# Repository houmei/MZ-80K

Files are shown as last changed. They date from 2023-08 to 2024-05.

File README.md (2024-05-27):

# MZ-80K

## 更新履歴
2024.5.27 U4 74LS14 RESETと*RESETの入れ替わり修正  
2024.5.27 U47 74154 pin18とpin19の入れ替わり修正  
2023.9.14 訂正 CPUにINT入力追加、RAMの100pFディレイ * RAS1 → *CAS  
2023.8.20 公開  

## 機種別情報
MZ-80K2は2色LEDから赤/緑の個別LEDに変更。  
MZ-80K2/MZ-80K2EはCPUが直付け、リセット周辺回路(U31 74121)とリセットスイッチが省略。  

## 新旧基板
ロジック基板はMZ-80Kでの初期版とそれ以降の後期版が存在する。初期版と後期版の違いはROMと電源コネクタ。  
+ 初期基板 M-ROM 2708 x4、CGROM 2708 x2、電源コネクタ molex 5198/5283 (5.08mmピッチ)  
+ 後期基板 M-ROM 2532 x1、CGROM 2716 x1、電源コネクタ JST 4P-LV/B4P-LV-TA (8.0mmピッチ)

電源コネクタ情報：[@mono_Pさんより](https://twitter.com/momo_P/status/1702351033270481181)

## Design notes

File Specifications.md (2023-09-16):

#

+ CPU: Z80 2MHz
+ Memory: Monitor-ROM 4KB , RAM 48KB(Max)
+ Display: 10"CRT 40 x 25 Characters VRAM 1KB 60Hz(V),15.75kHz(H)
+ Cassete: 1200 baud
+ Weight: Approx. 13kg
+ Dimensions: 410 x 270 x 470 mm
+ PSU: DC5V 1.6Amax DC12V 1.6Amax DC-5V 0.2Amax Approx. 45W

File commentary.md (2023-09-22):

# MZ-80K 回路図解説

## CPU
+ CPU(U46 Z80)のバスバッファはU36,U37 LS241 x2、アドレスバッファはU44,U45 LS244 x2。  
+ 制御信号もU35 LS244でバッファ。  
+ CLK入力はレベルを合わせるため330Ωでプルアップ。  
+ メモリWAITは未使用。  
+ *NMI は未使用。  
+ *INT はTIMER(U18 8253)のOUT2(を反転したもの)に接続。  
+ マニュアルリセットはU31 74121によるワンショット。0.7CR = 0.7x0.01ux15k = 0.1ms。一部機種(K2Eなど)では省略。  

※CPUに直接接続されている信号は * INT 程度でかなりガードされている印象。  

## メモリ
### RAM
+ DRAM 8個 x3ブロックで最大48KB、基本は16KB。  
+ RAMブロックのうち最初のRAM1ブロックは16KB(4116 x8)、RAM2,RAM3ブロックは4KB(4027 x8)または16KB(4116 x8)の選択式。  
+ *CASはU54E,U54DのLS04 2段に加えて100pFを使用し信号を少し遅らせている。  
### RAMSEL
+ U50 LS244はM-ROMの出力とDRAMのDoutを受けてデータバスに接続。DRAMのDinはデータバスに直結。
+ U50 LS244はM-ROM/DRAMセレクトのリード時のみ開く。
+ U55B LS74出力のS1はDRAMの上位/下位アドレス切り替え。  
+ RSEL1,2,3および*RAS1,2,3はCS1ジャンパでRAMブロックの範囲を16KBまたは4KBで選択する。  
### DECODE
+ U47 74154で64KBのメモリ空間を4Kバイト単位に分割。
+ IO領域は$ExxxをU30 LS42でデコードし8255,8253をセレクト。
+ U57 74150、U58 LS00は4K DRAMに必要な論理。
+ U56 S157、U53 S157でRAS/CASアドレスを生成。

※ *CASをドライブするU54D LS04の負荷は重いのではないか？  
※U54E LS04とU54D LS04の間に100pFを入れてもよかったのでは  

## ビデオ

## I/O

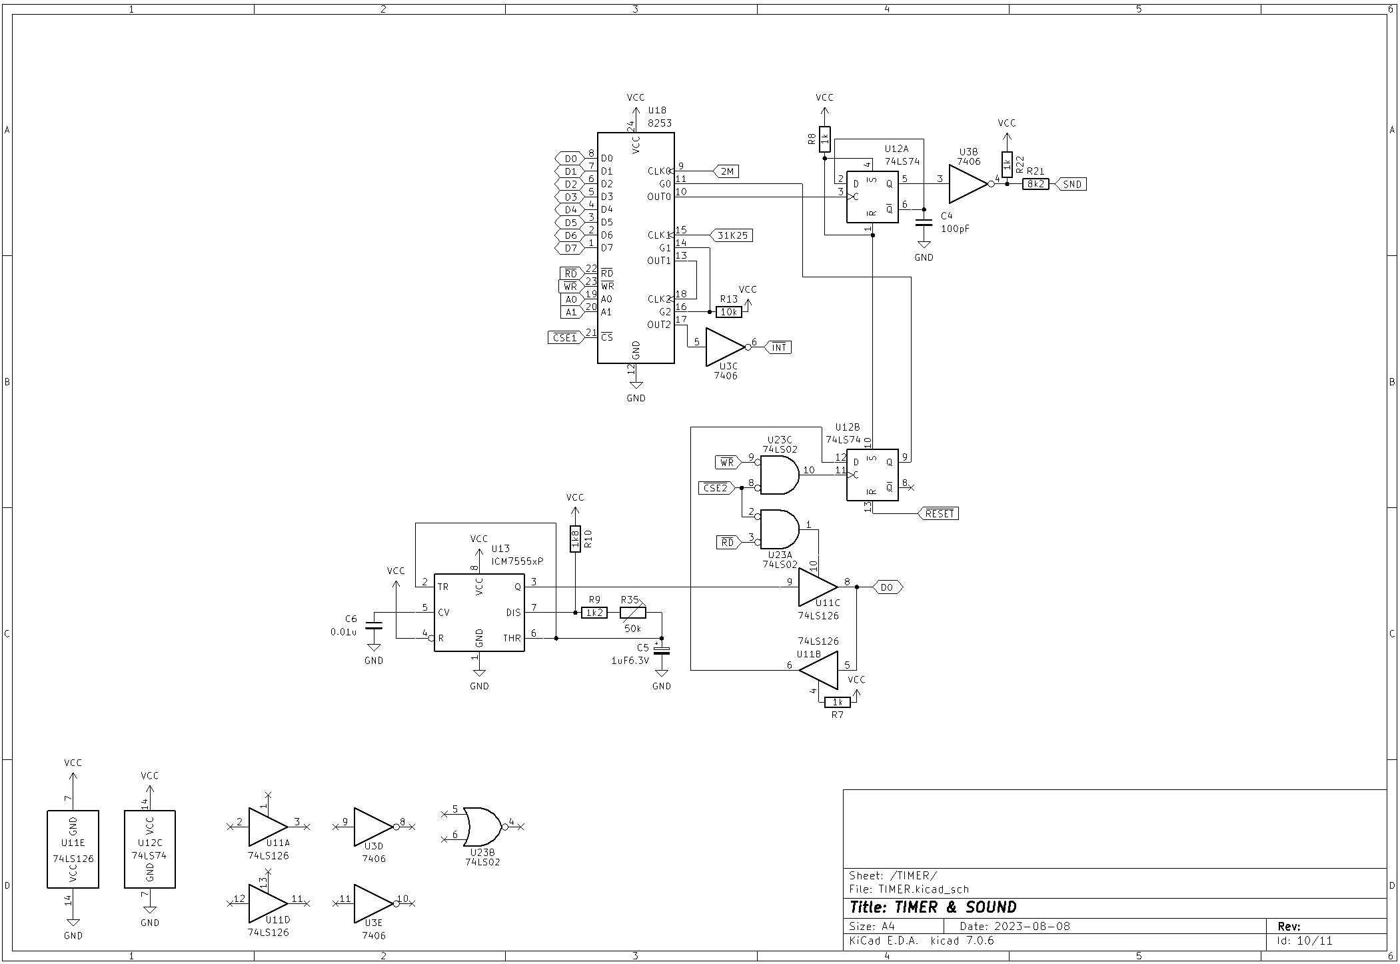
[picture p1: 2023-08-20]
img/10TIMER.png

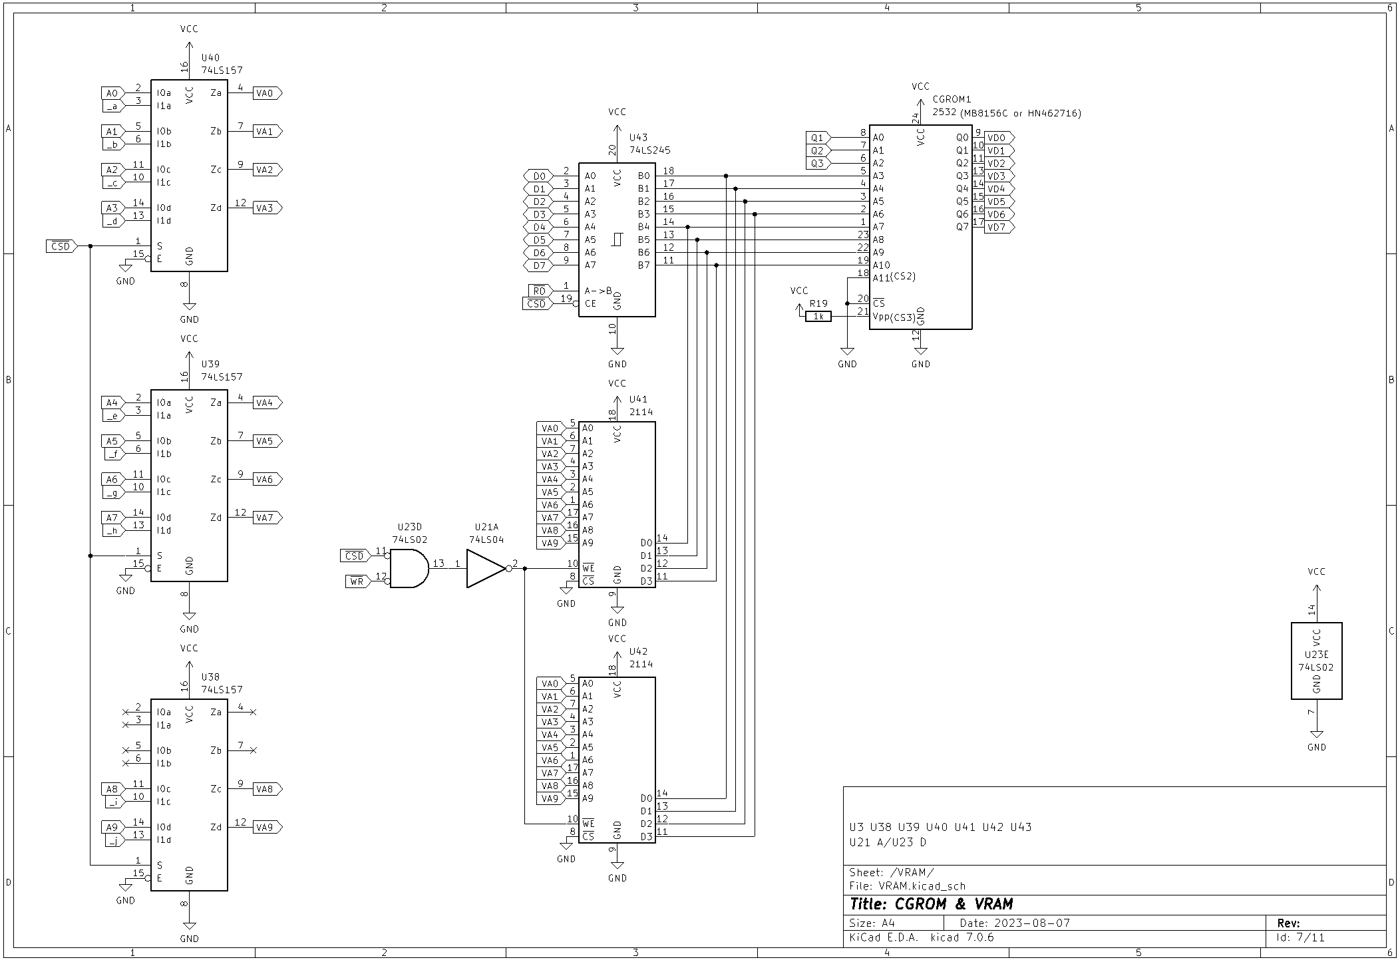
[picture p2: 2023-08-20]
img/07VRAM.png

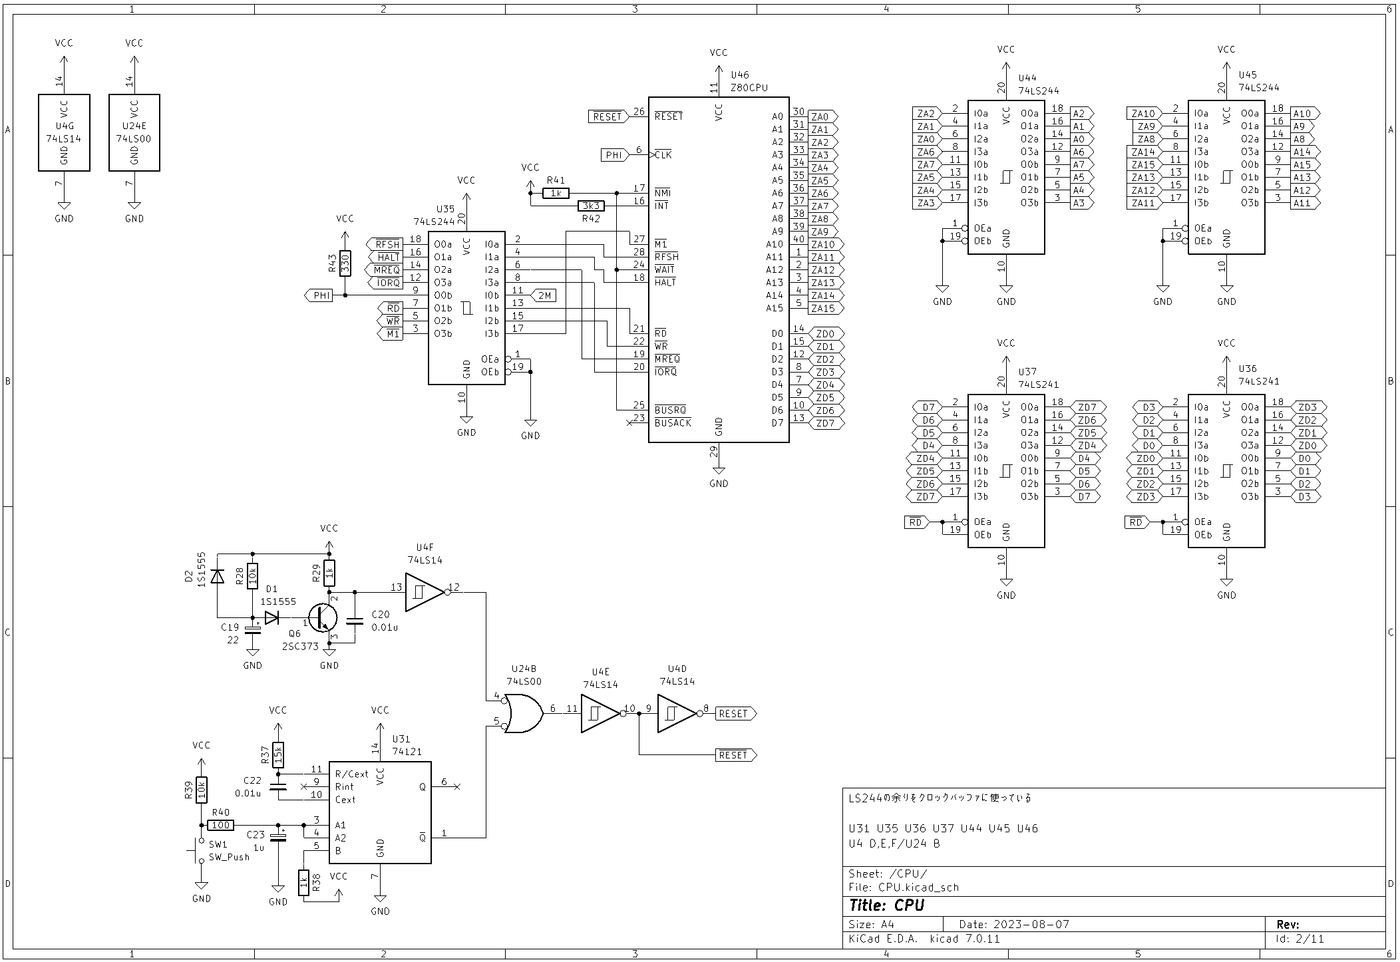
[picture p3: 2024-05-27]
img/02CPU.png

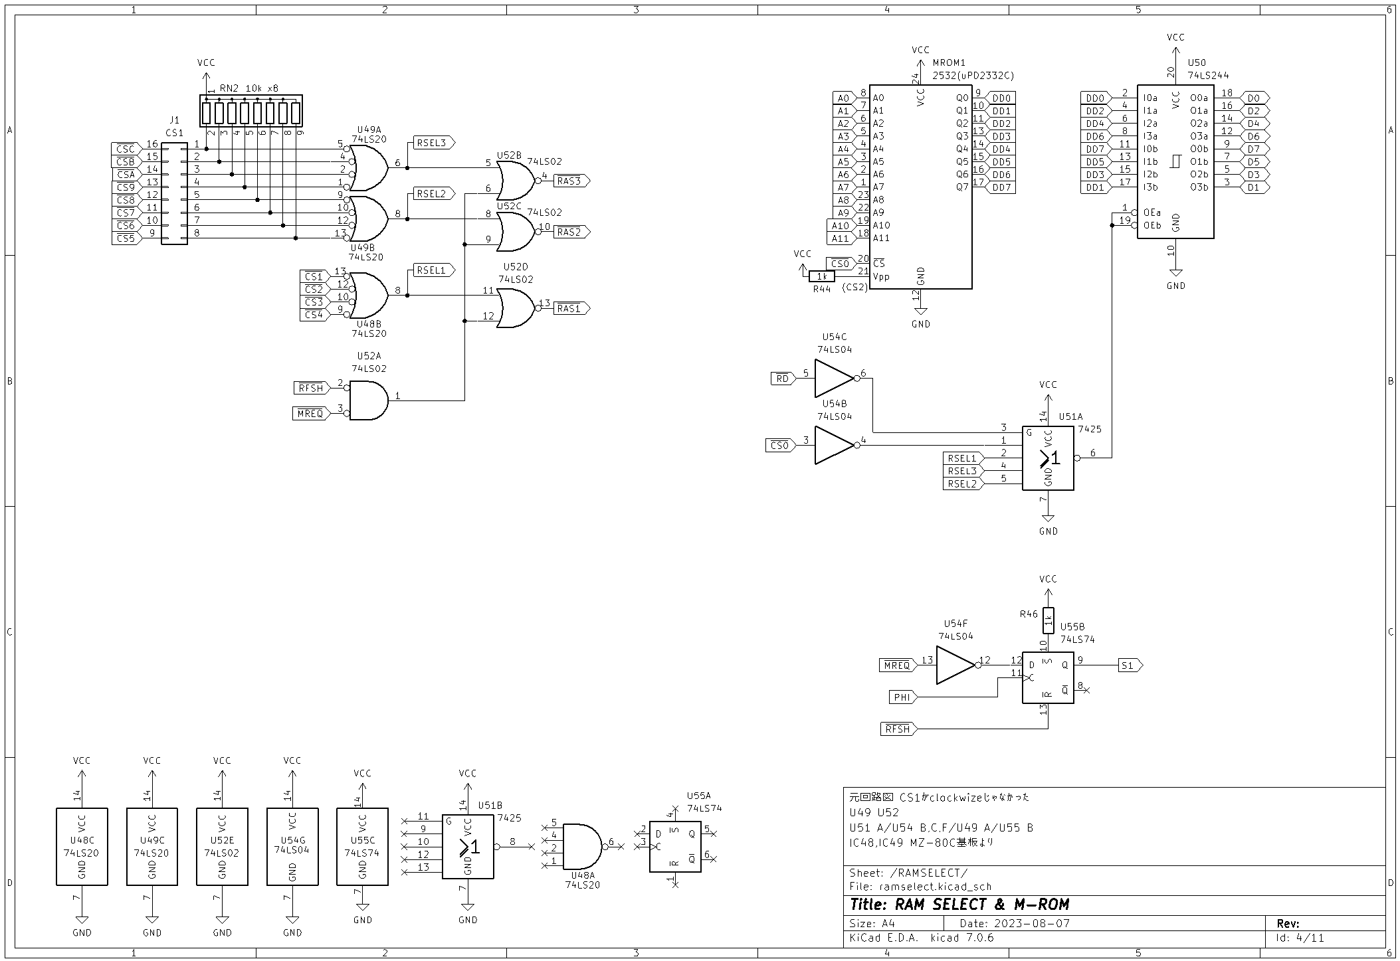
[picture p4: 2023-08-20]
img/04RAMSEL.png

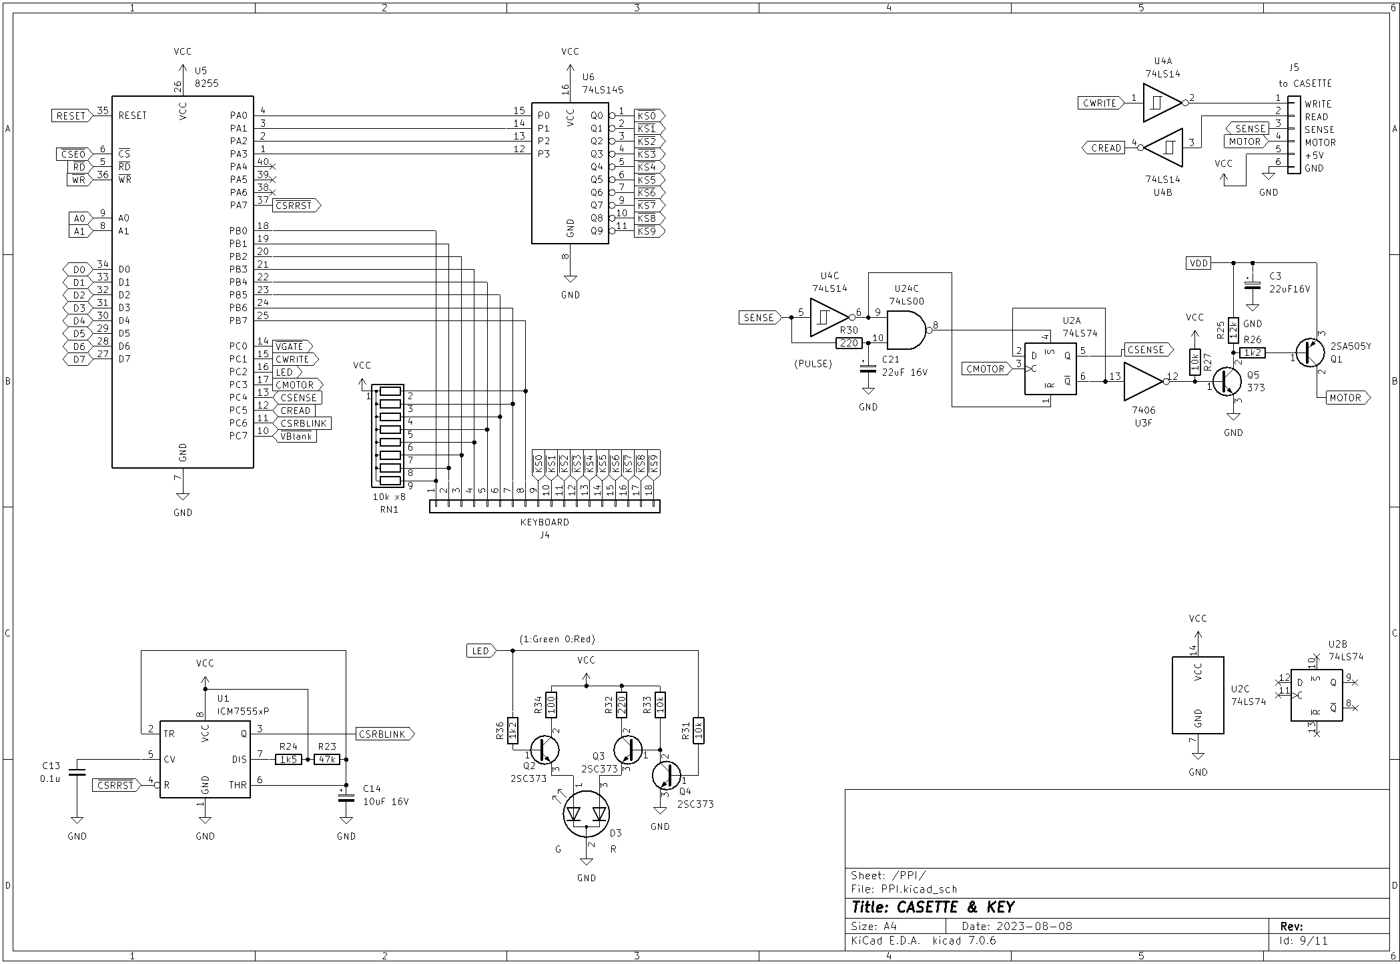
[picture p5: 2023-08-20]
img/09PPI.png

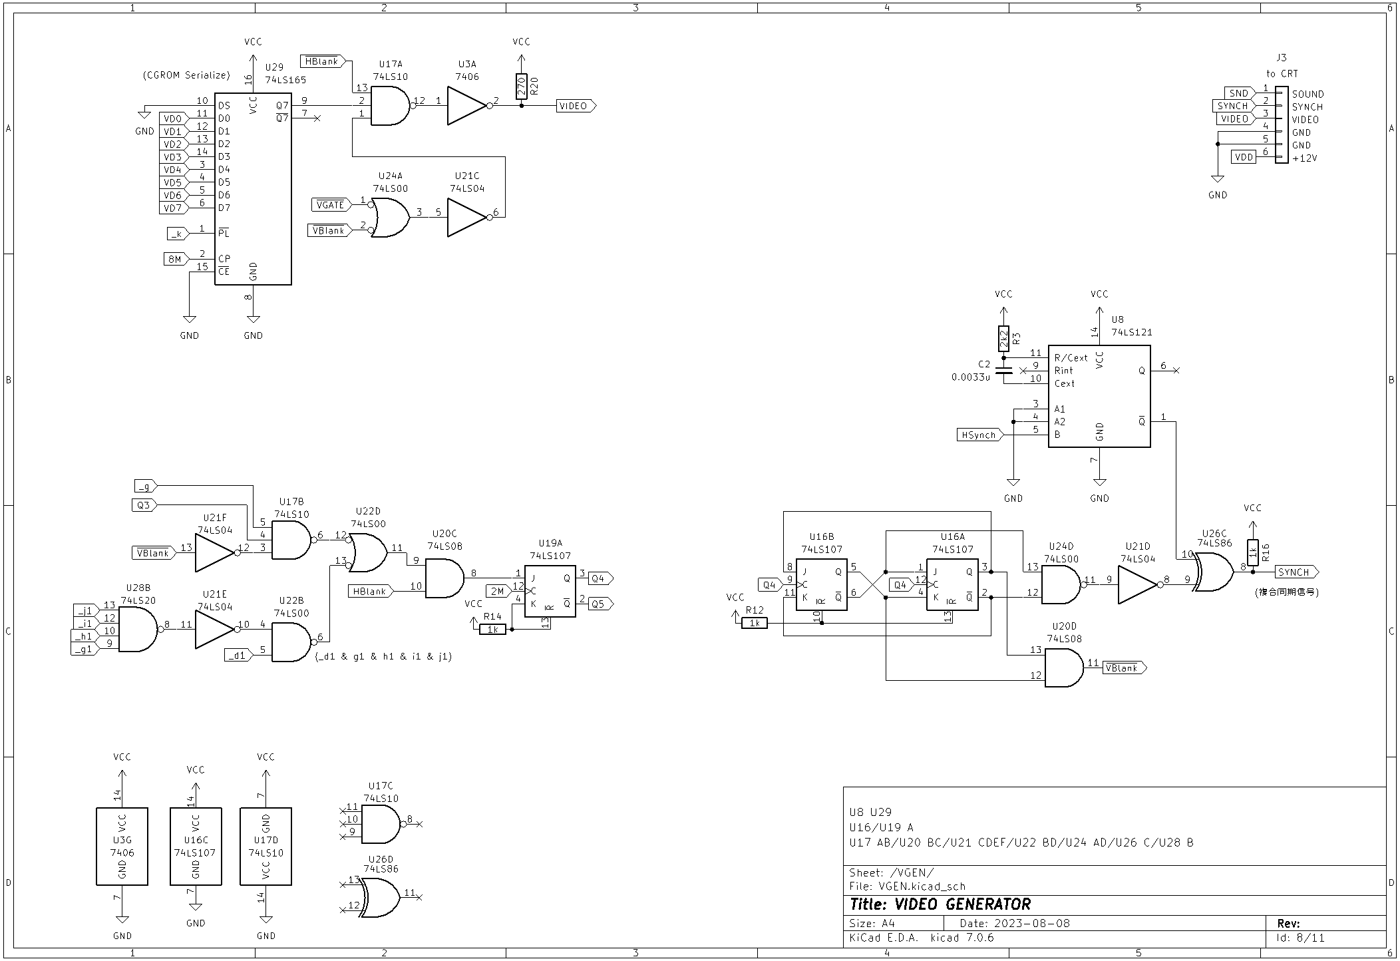
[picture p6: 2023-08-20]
img/08VGEN.png

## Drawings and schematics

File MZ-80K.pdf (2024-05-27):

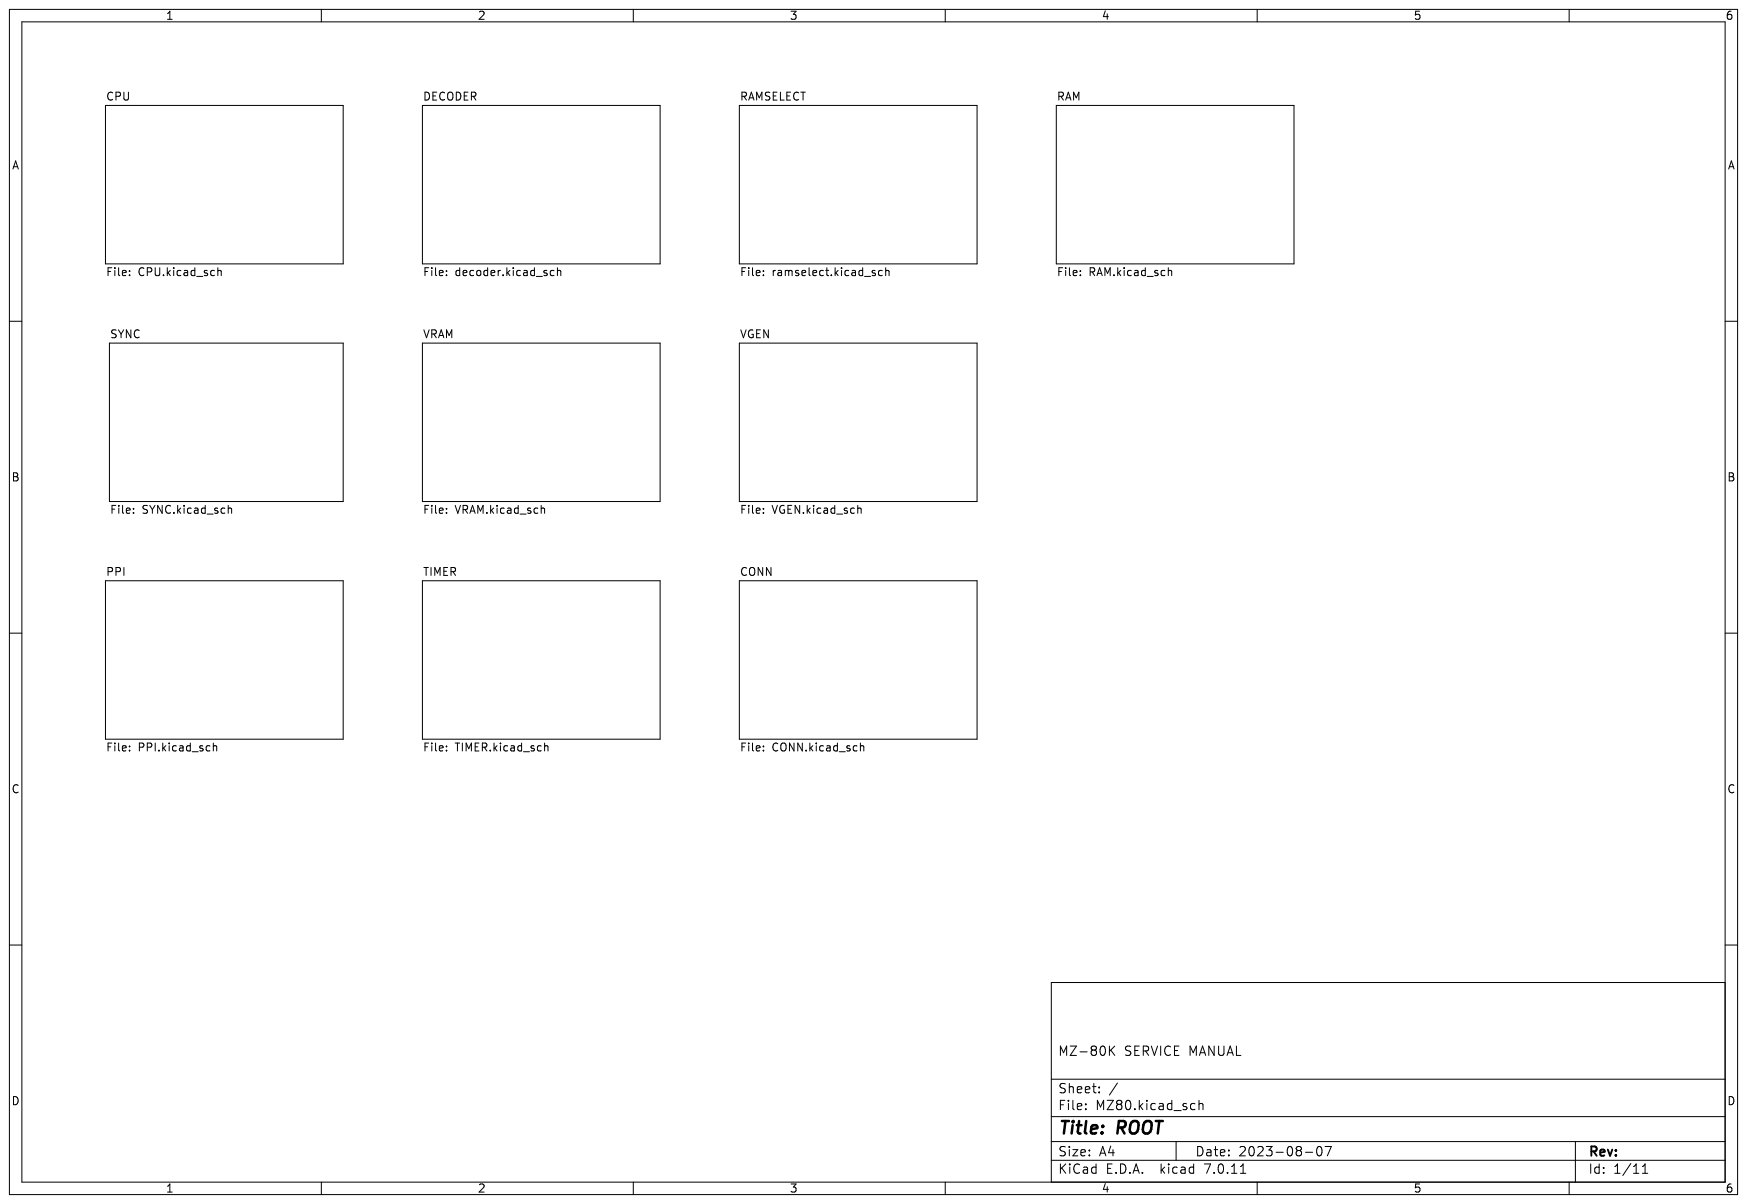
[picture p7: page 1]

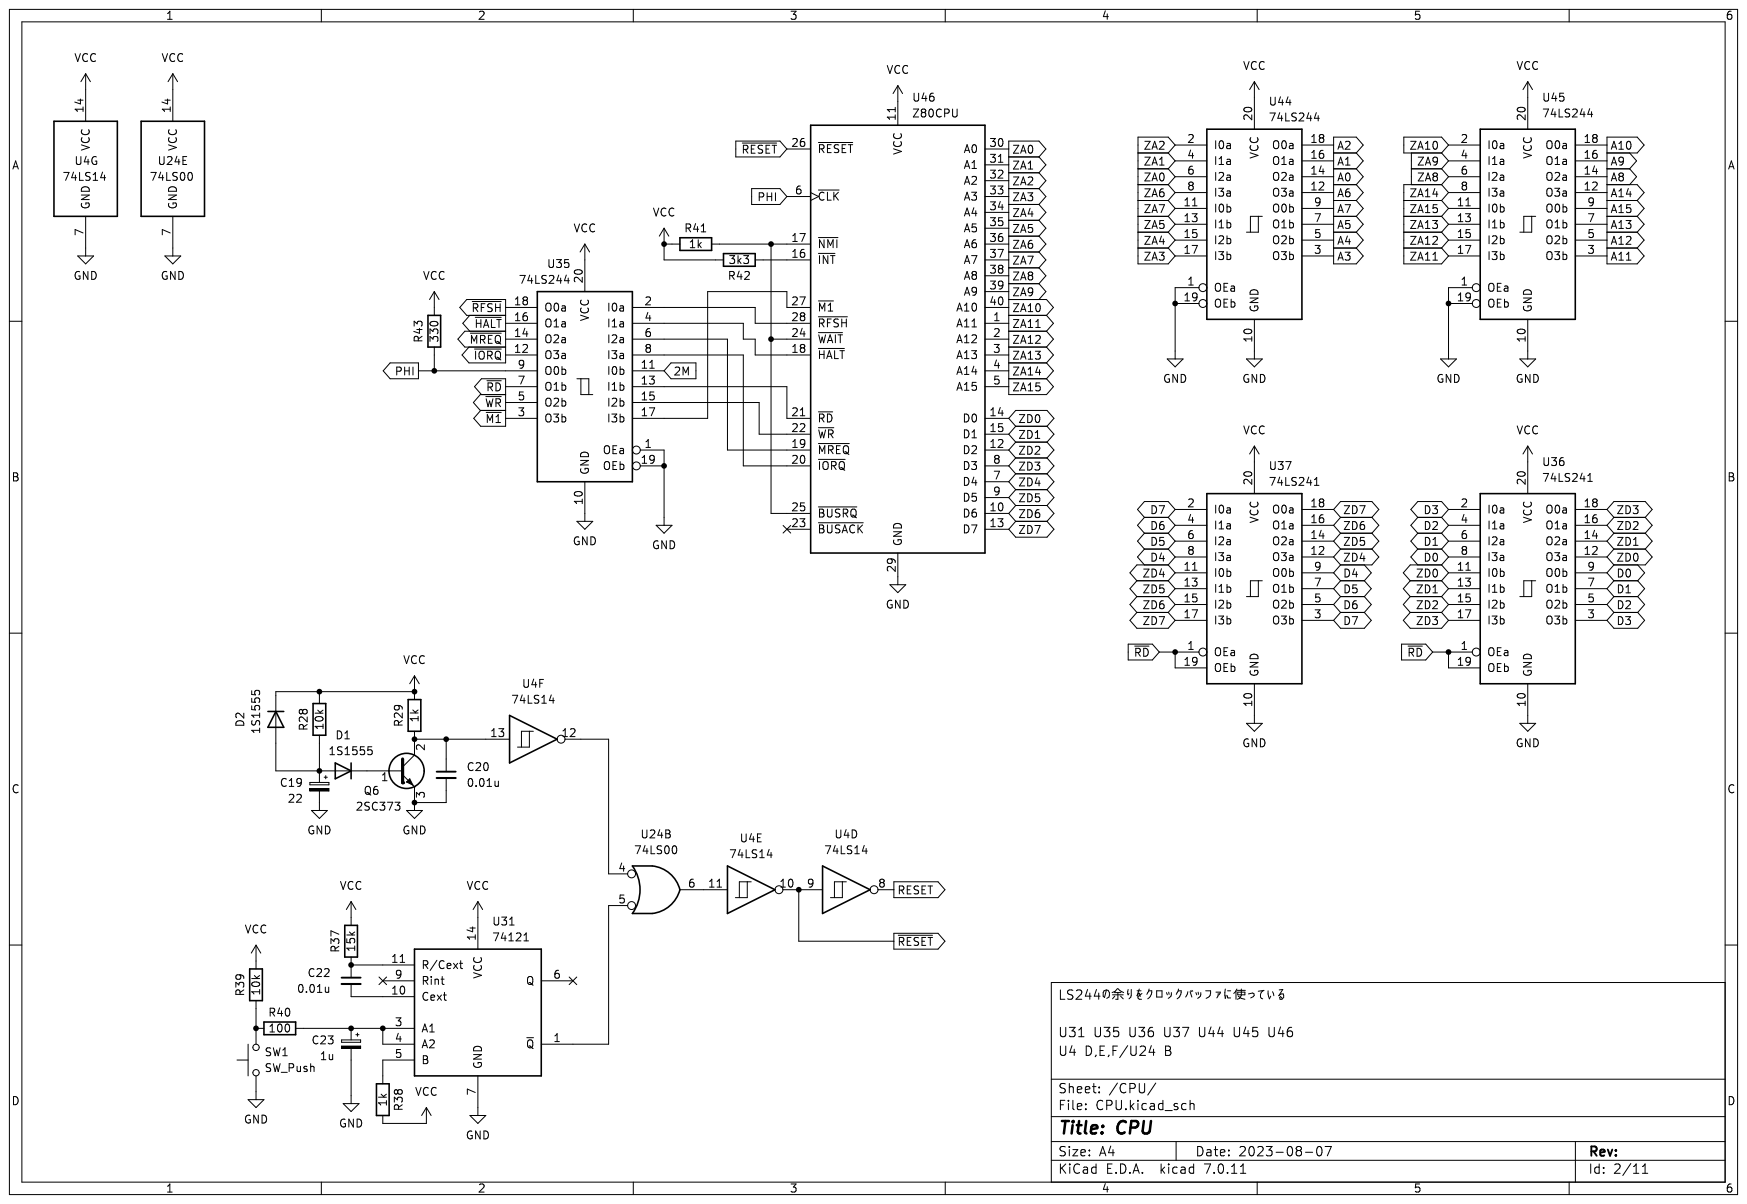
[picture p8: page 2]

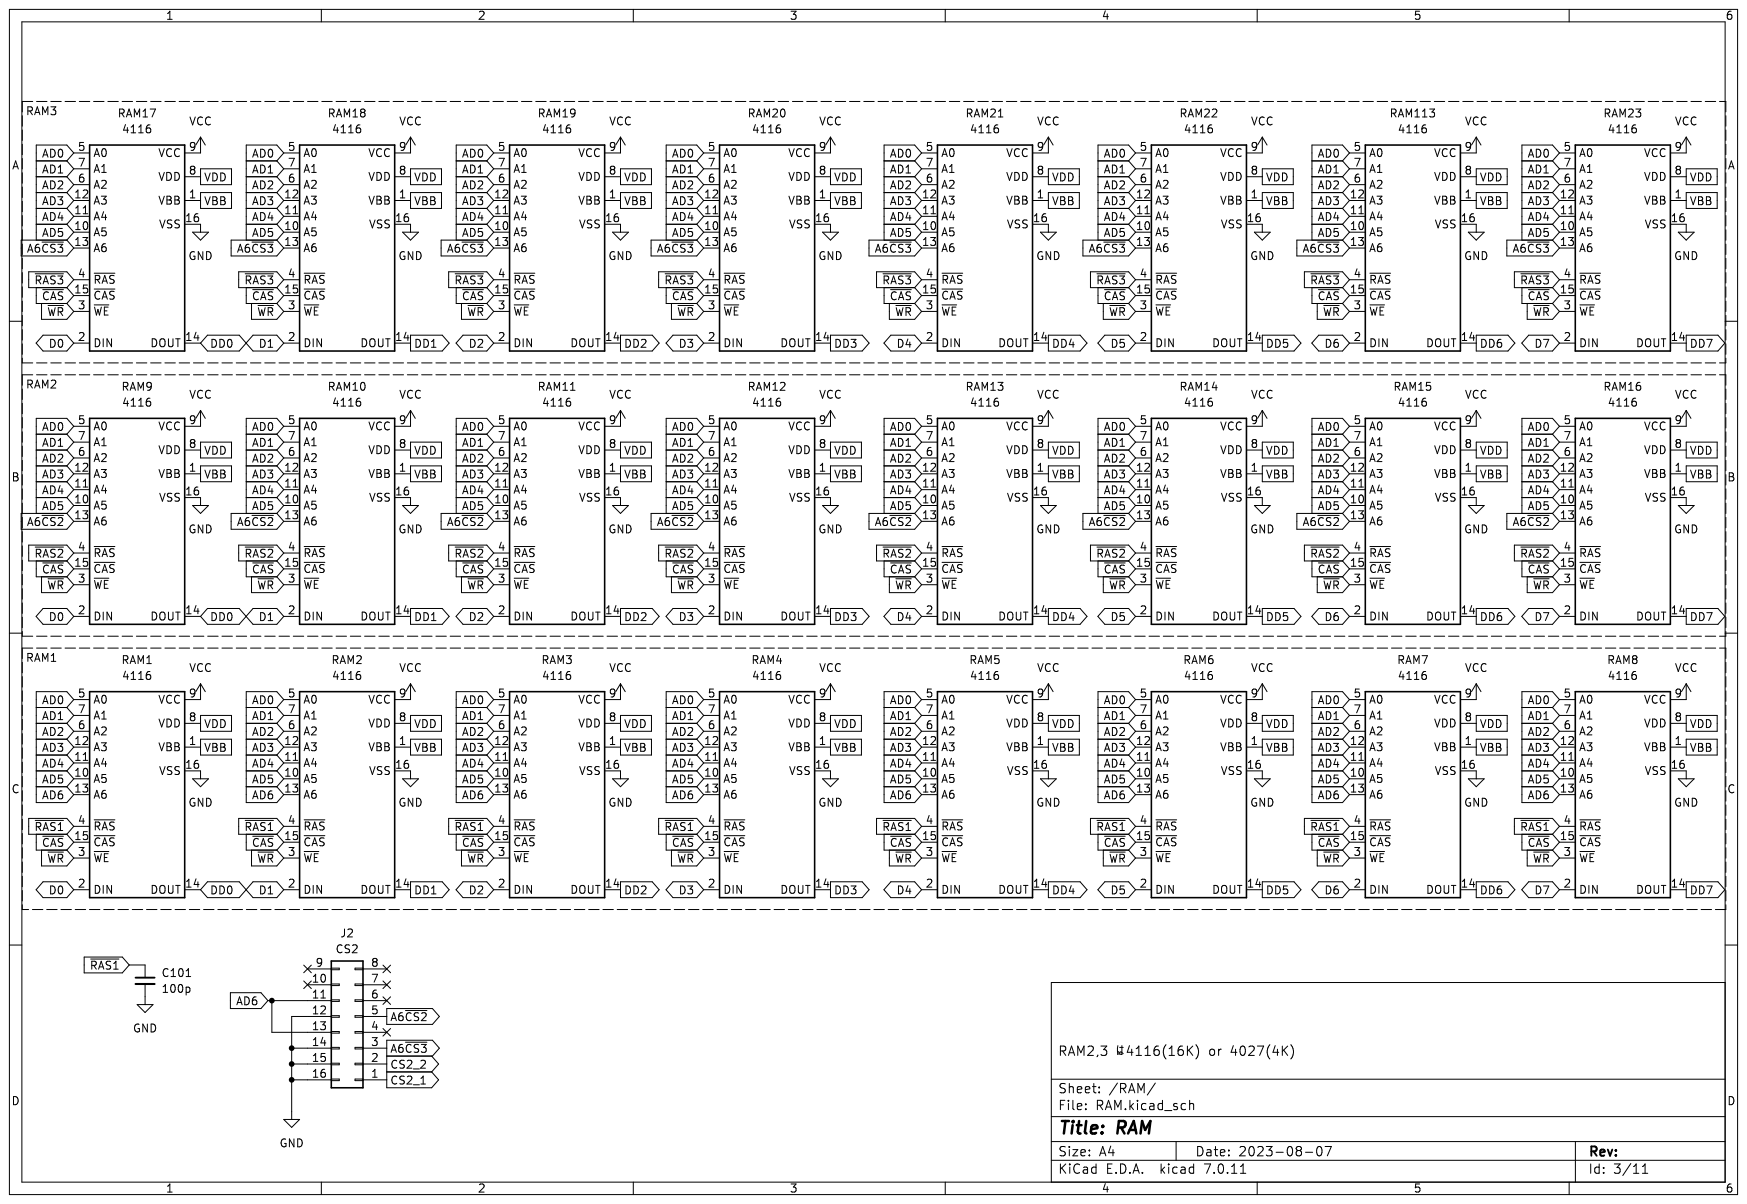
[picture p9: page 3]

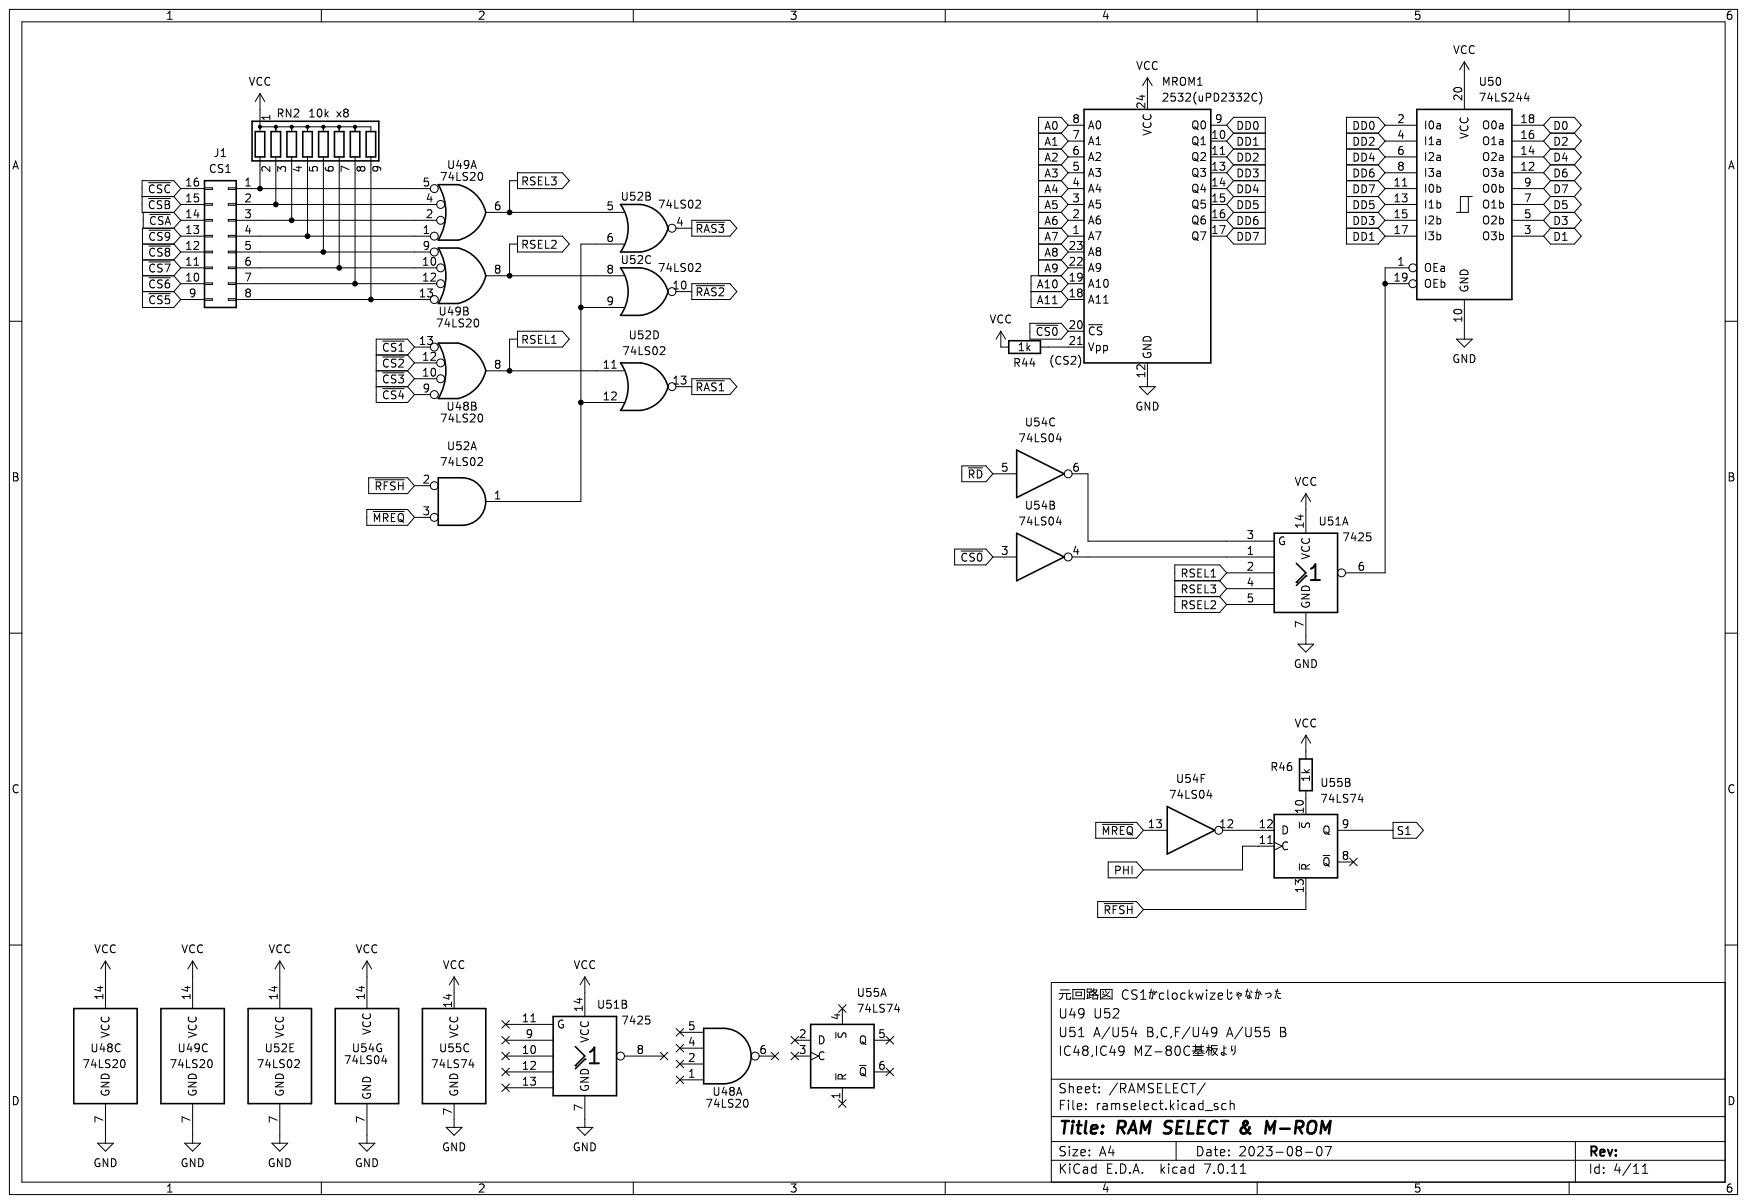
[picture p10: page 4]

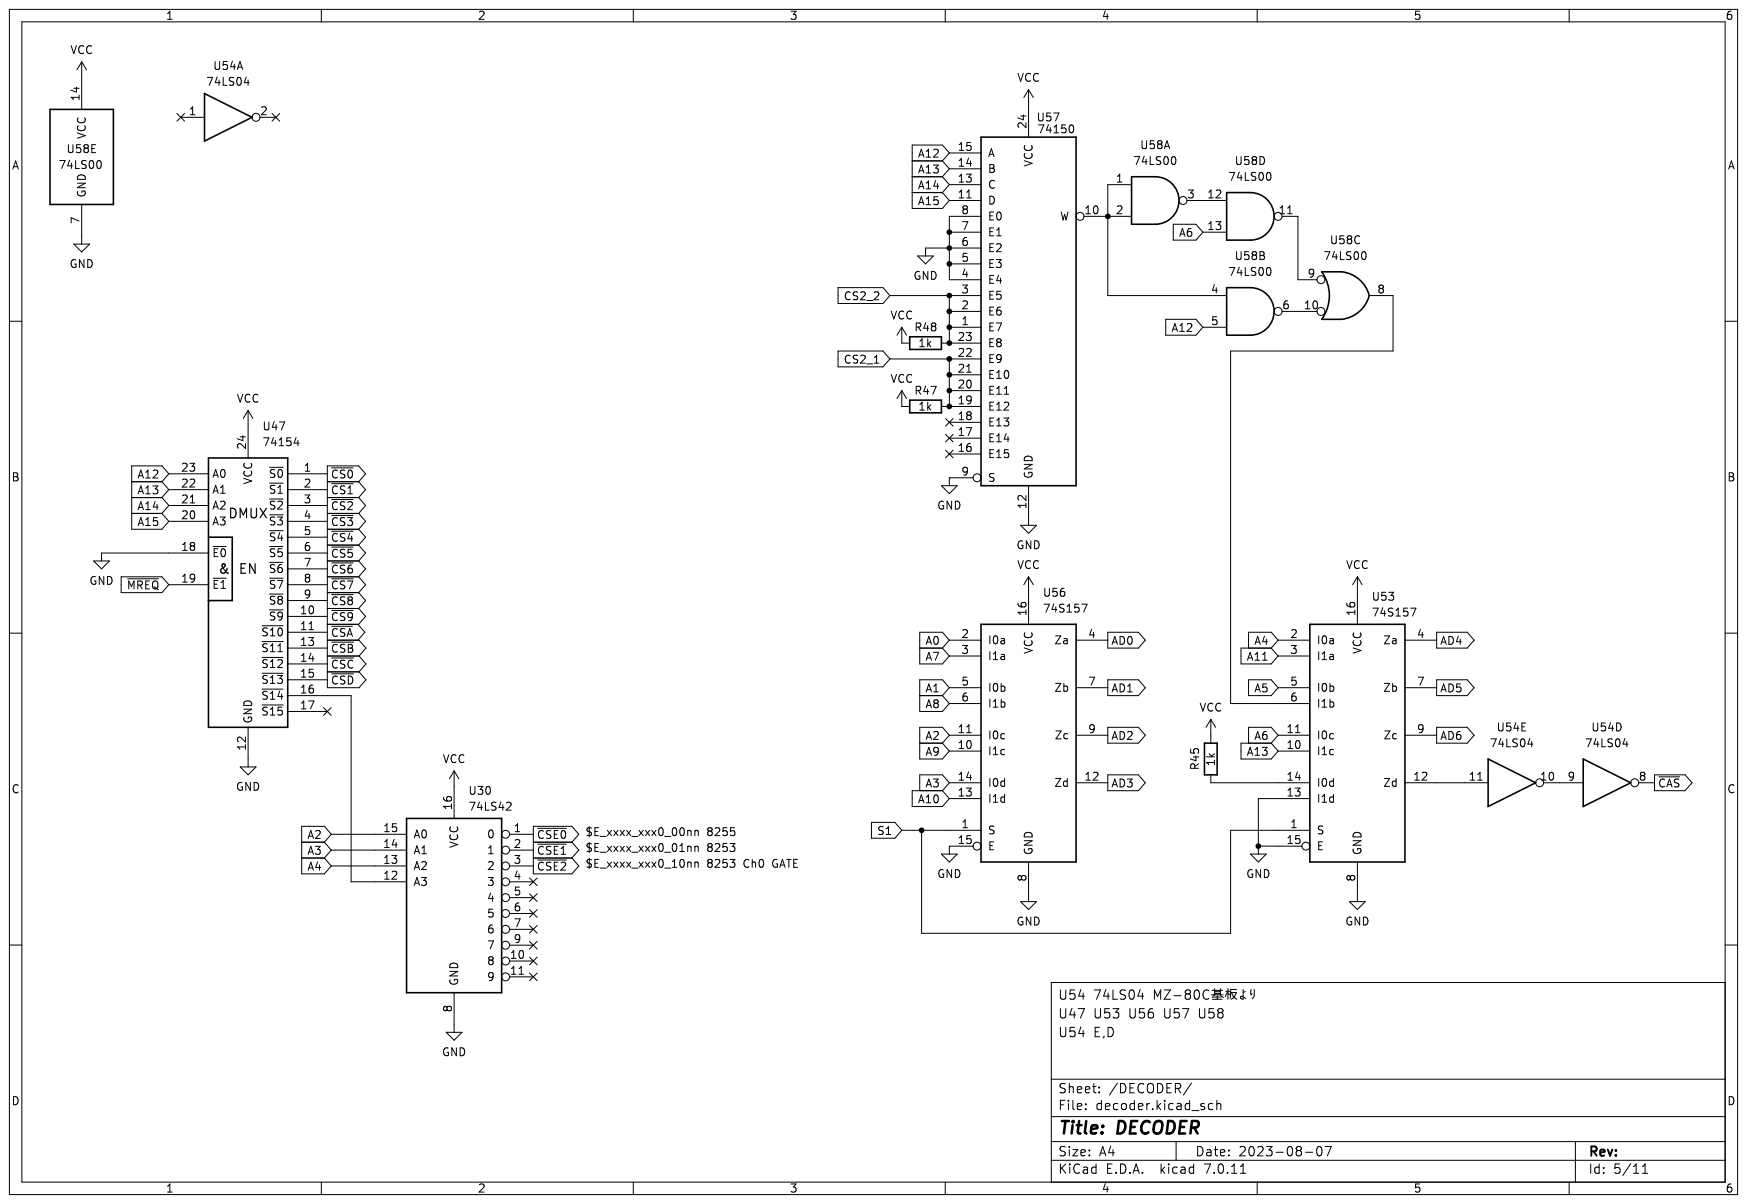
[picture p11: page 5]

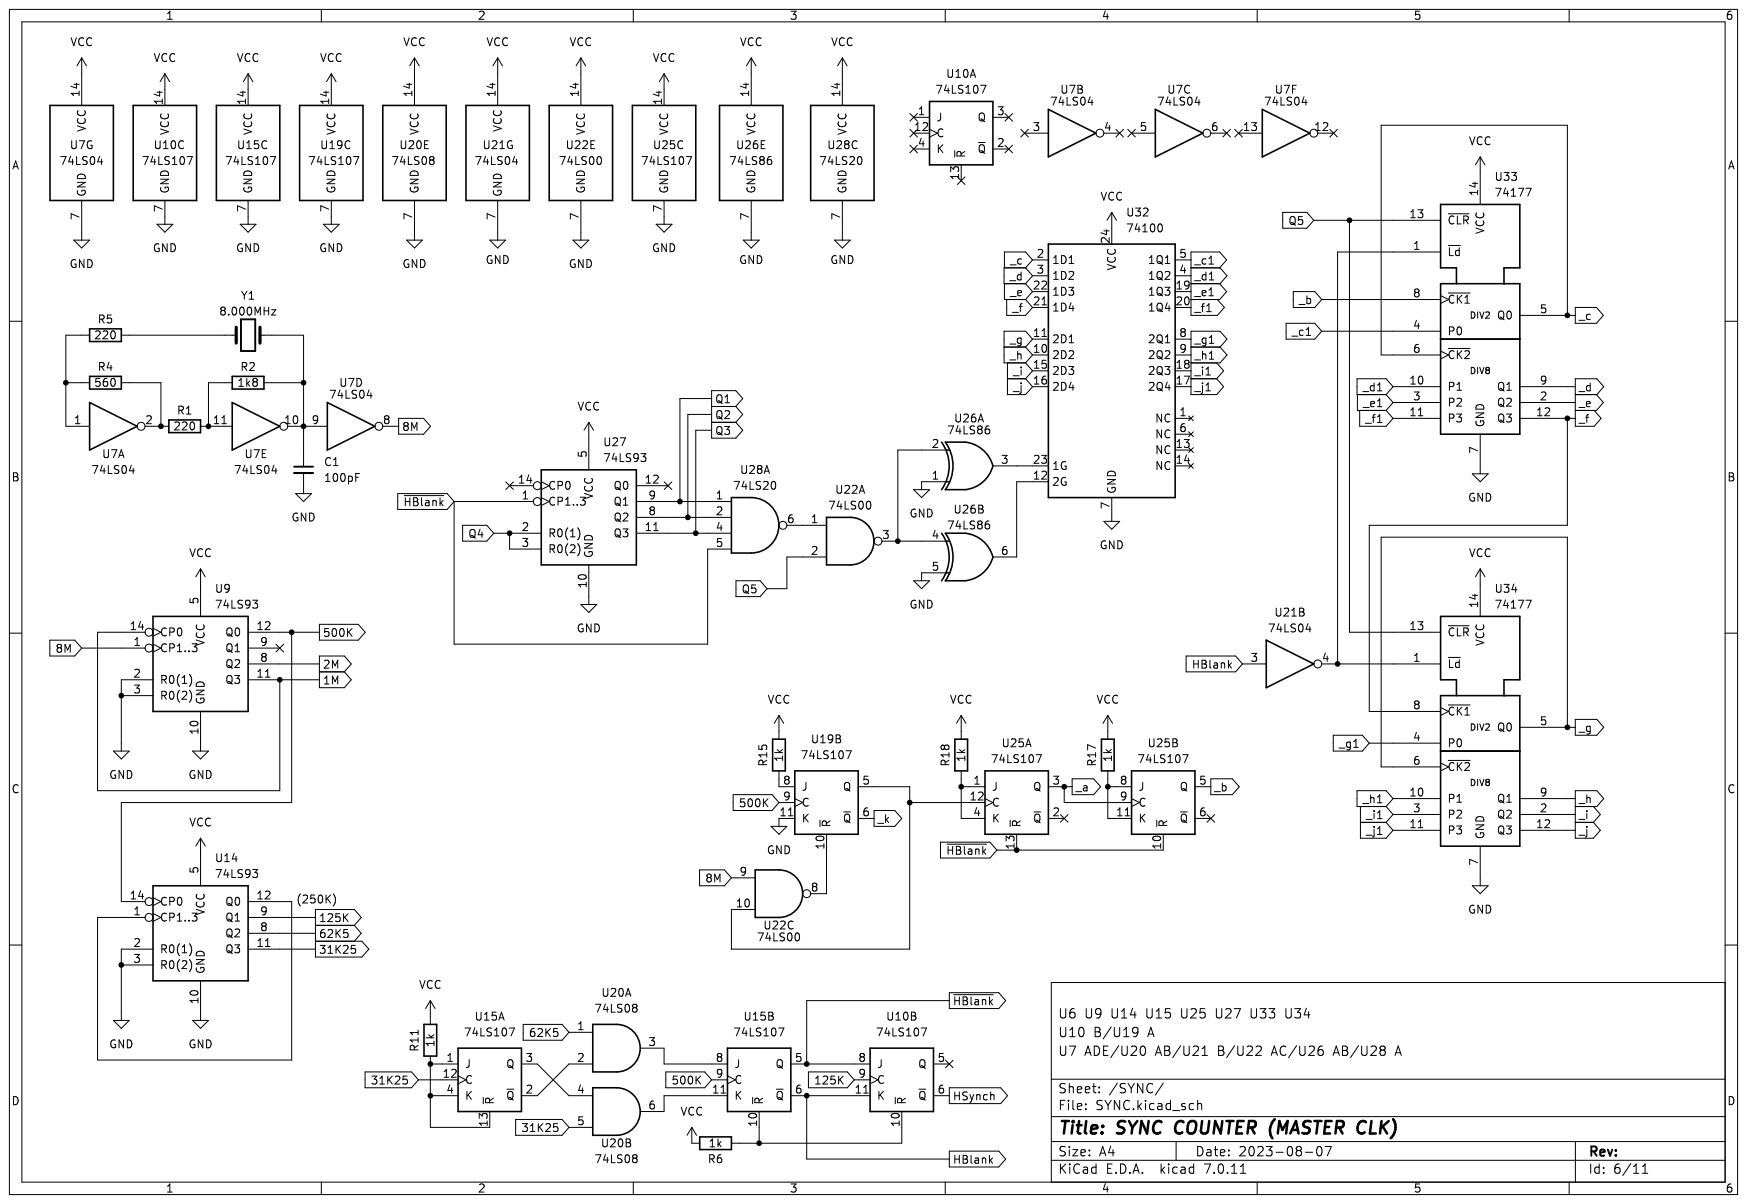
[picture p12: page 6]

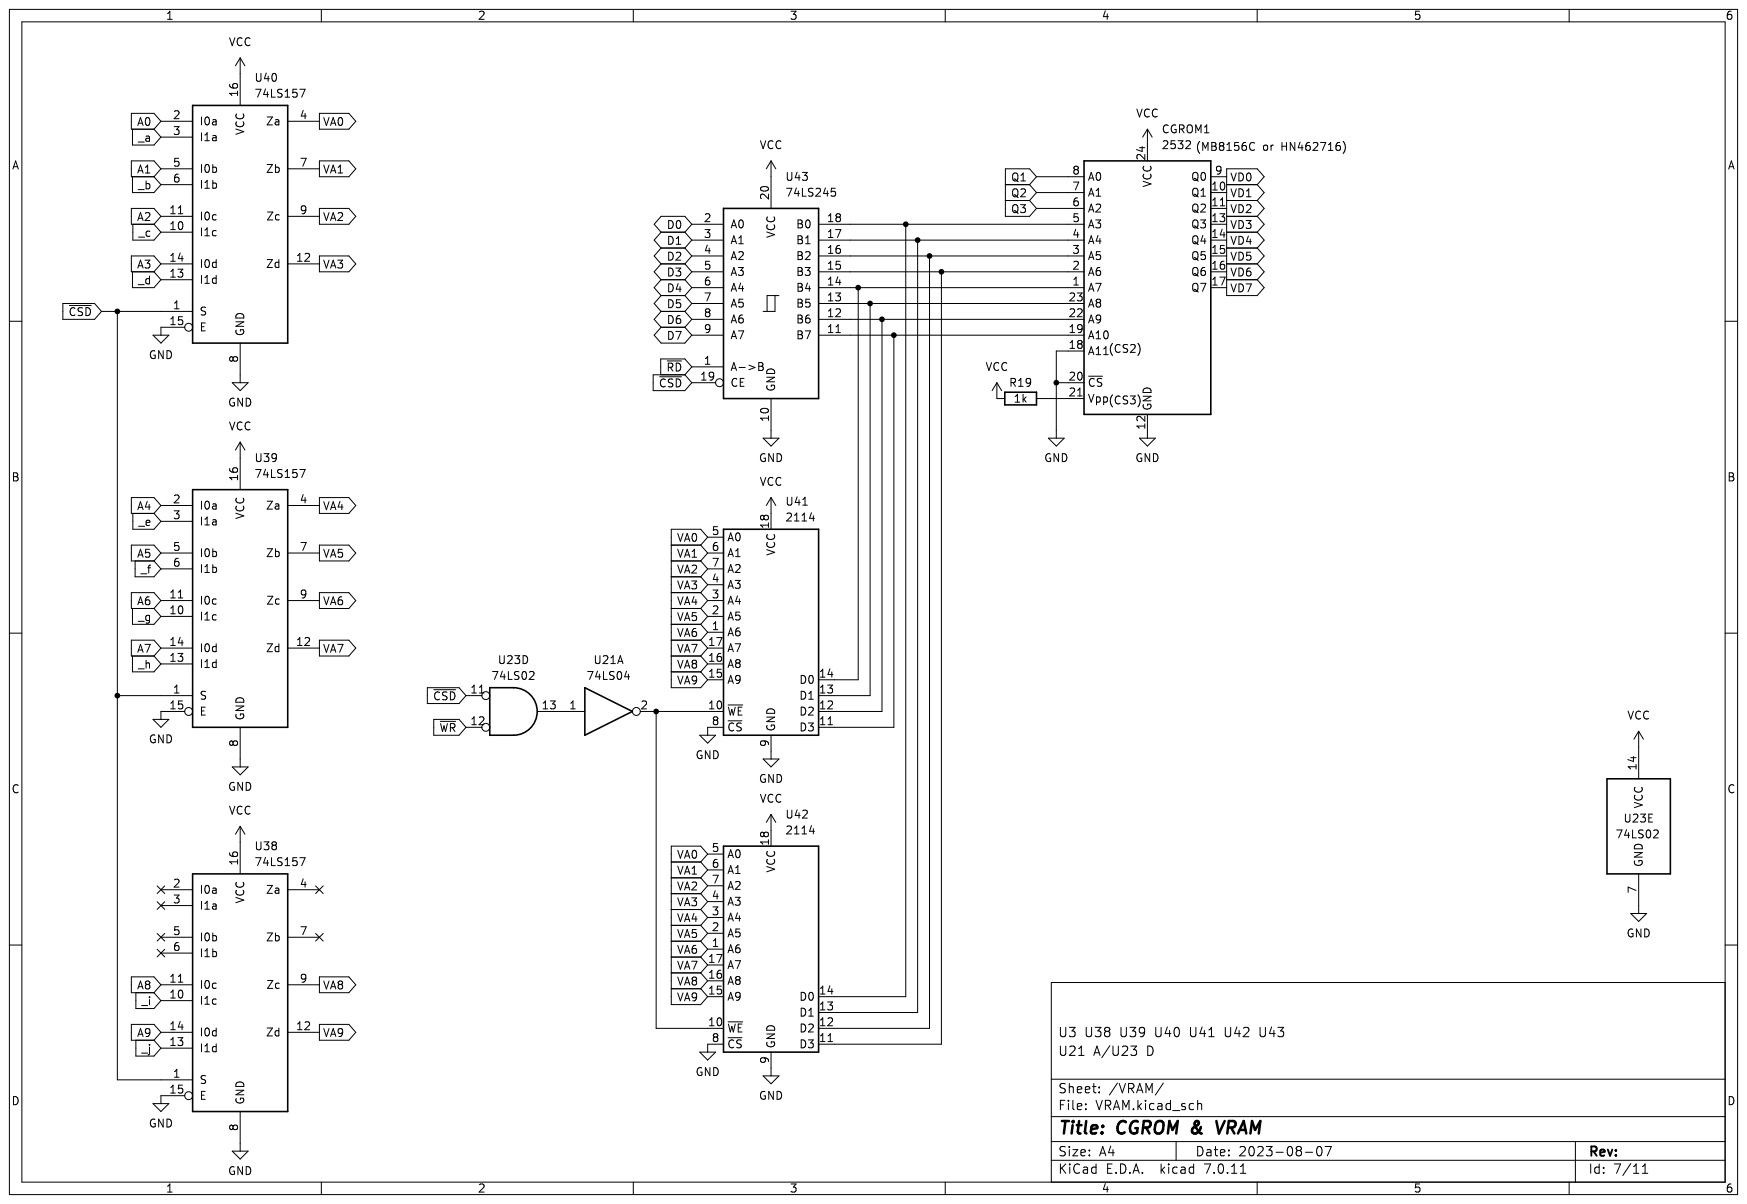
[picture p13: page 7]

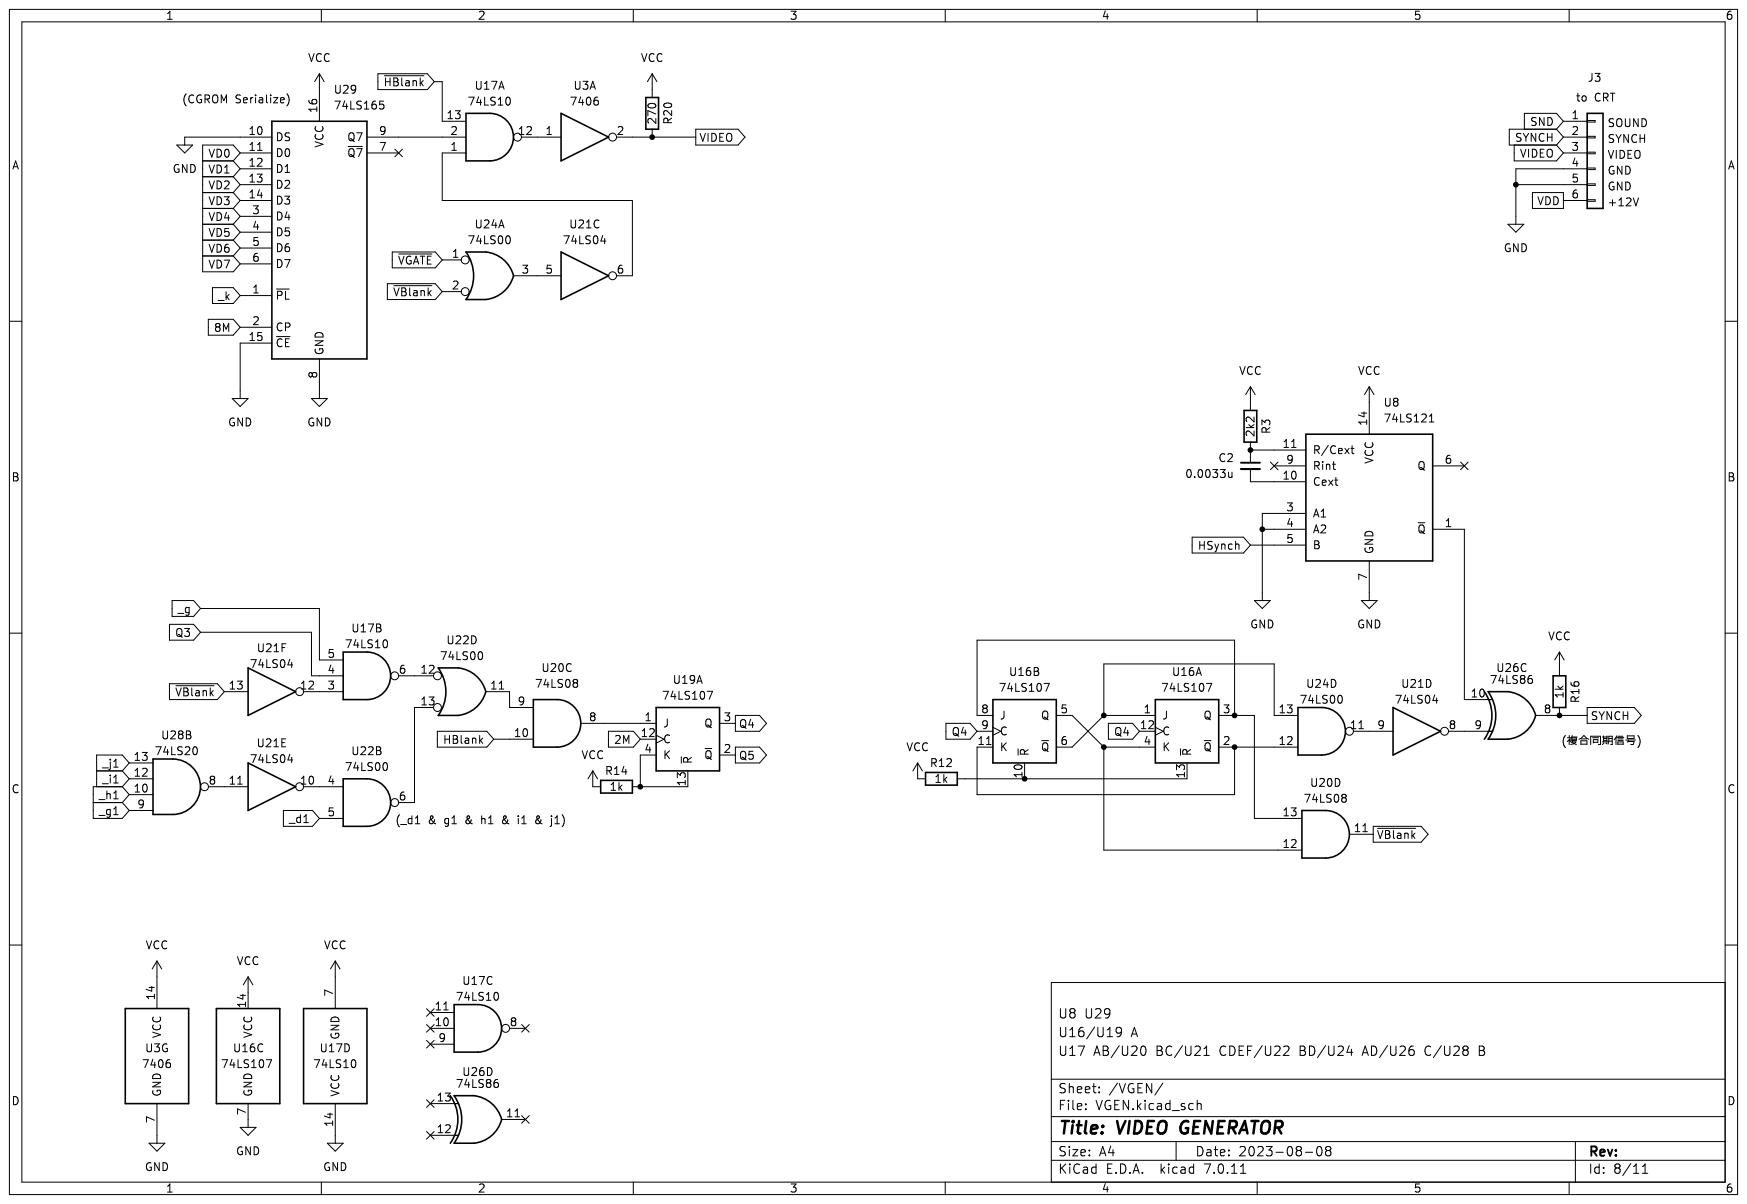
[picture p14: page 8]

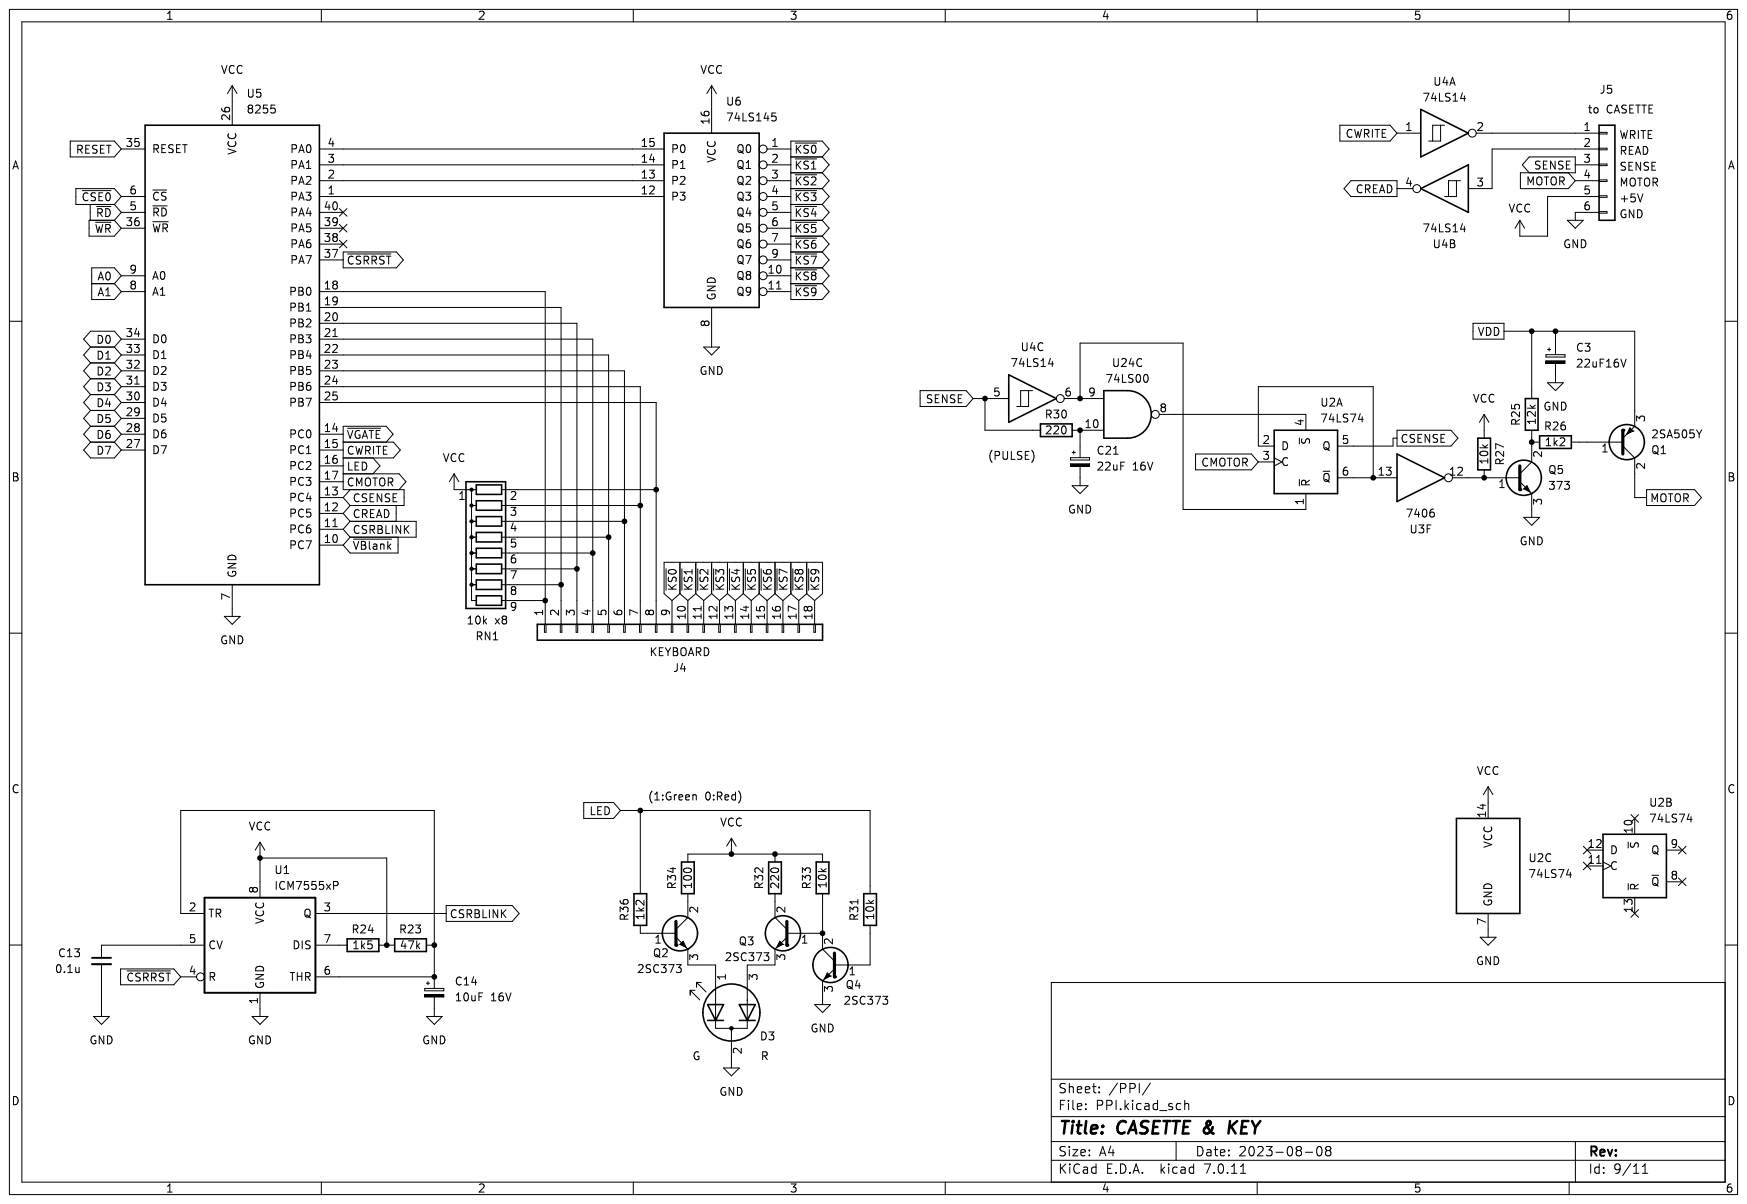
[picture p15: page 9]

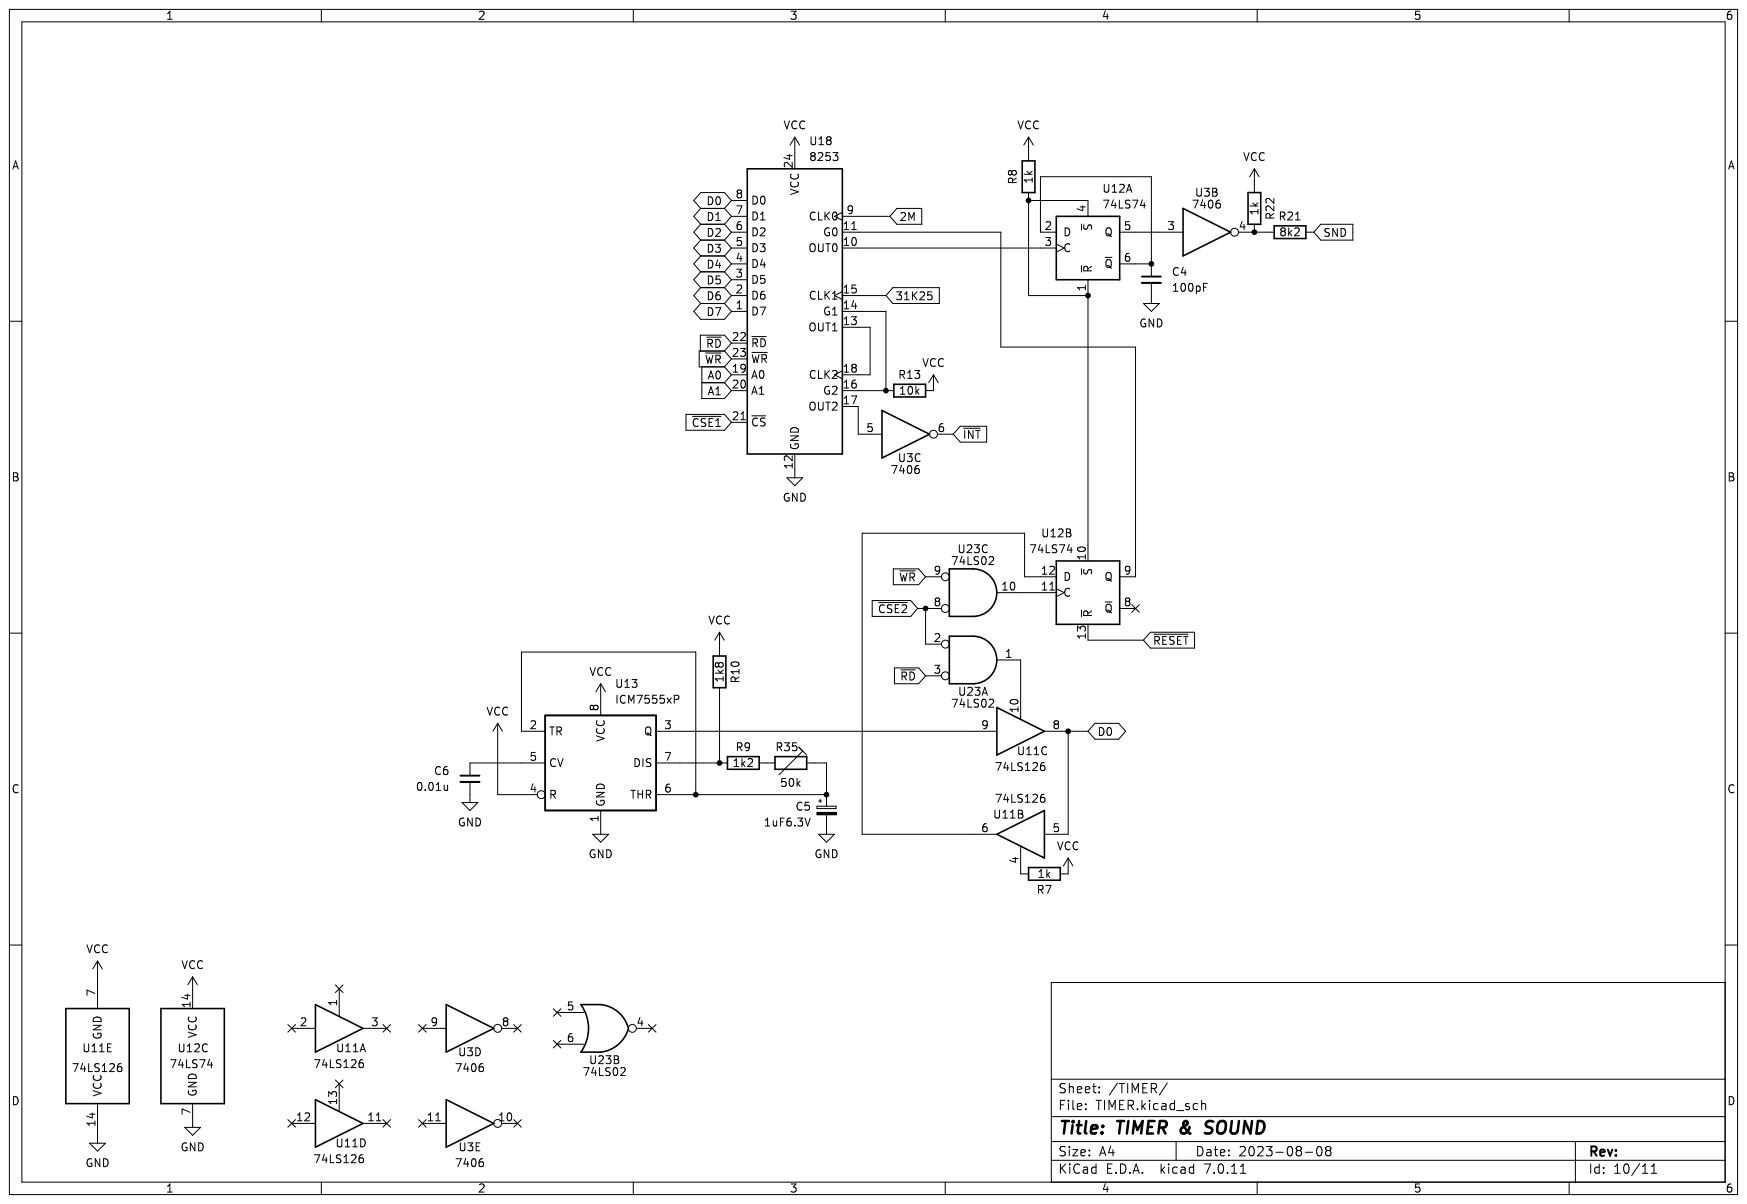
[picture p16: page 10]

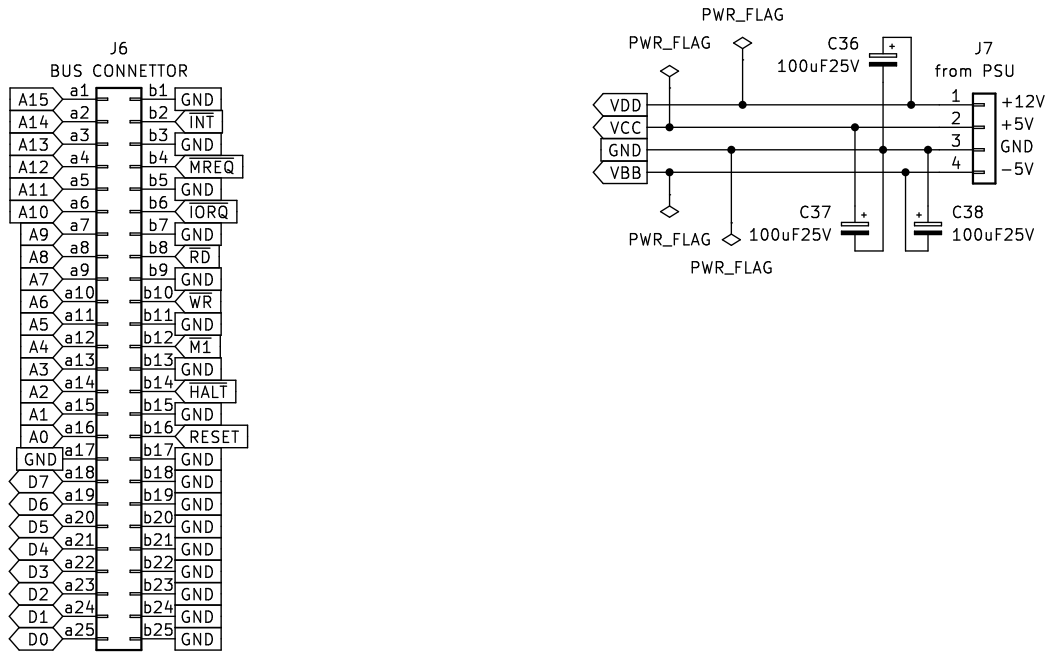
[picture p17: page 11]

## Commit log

2024-05-27 fix U47 pin18 pin19
    [CPU.kicad_sch, PPI.kicad_sch, TIMER.kicad_sch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]
2024-05-27 fix RESET/*RESET
    [CPU.kicad_sch]
